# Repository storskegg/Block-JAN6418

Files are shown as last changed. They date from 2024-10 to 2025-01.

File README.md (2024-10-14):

# Block-JAN6418

A simple yet flexible gain stage based on the JAN6418 subminiature pentode.

## Features

- Filament supply options:
    - 2x resistor voltage drop
    - LM317L direct regulation
- Pentode/Triode mode:
    - Triode: Jumper (0 Ohm resistor) S2 to the plate
    - Pentode: Solder a resistor between S2 and the plate, and S2 and ground
    - Pentode: Solder leads to an off-board potentiometer in lieu of the two
      resistors
- Star ground: Every on-board ground connection has its own trace to `Sig_gnd`

## Background

I've been designing a blues harp preamp for a buddy of mine, and it occurred to
me that all valve gain blocks are essentially the same, just with some variance
in component values. Because I tend to have different ideas for an individual
gain block, and different ideas about interstage connections (capacitor types,
tone stack, delay/echo, etc), having this board allows me to play with different
ideas more easily than pulling up components from the breadboard, but at the
cost of components soldered into place.

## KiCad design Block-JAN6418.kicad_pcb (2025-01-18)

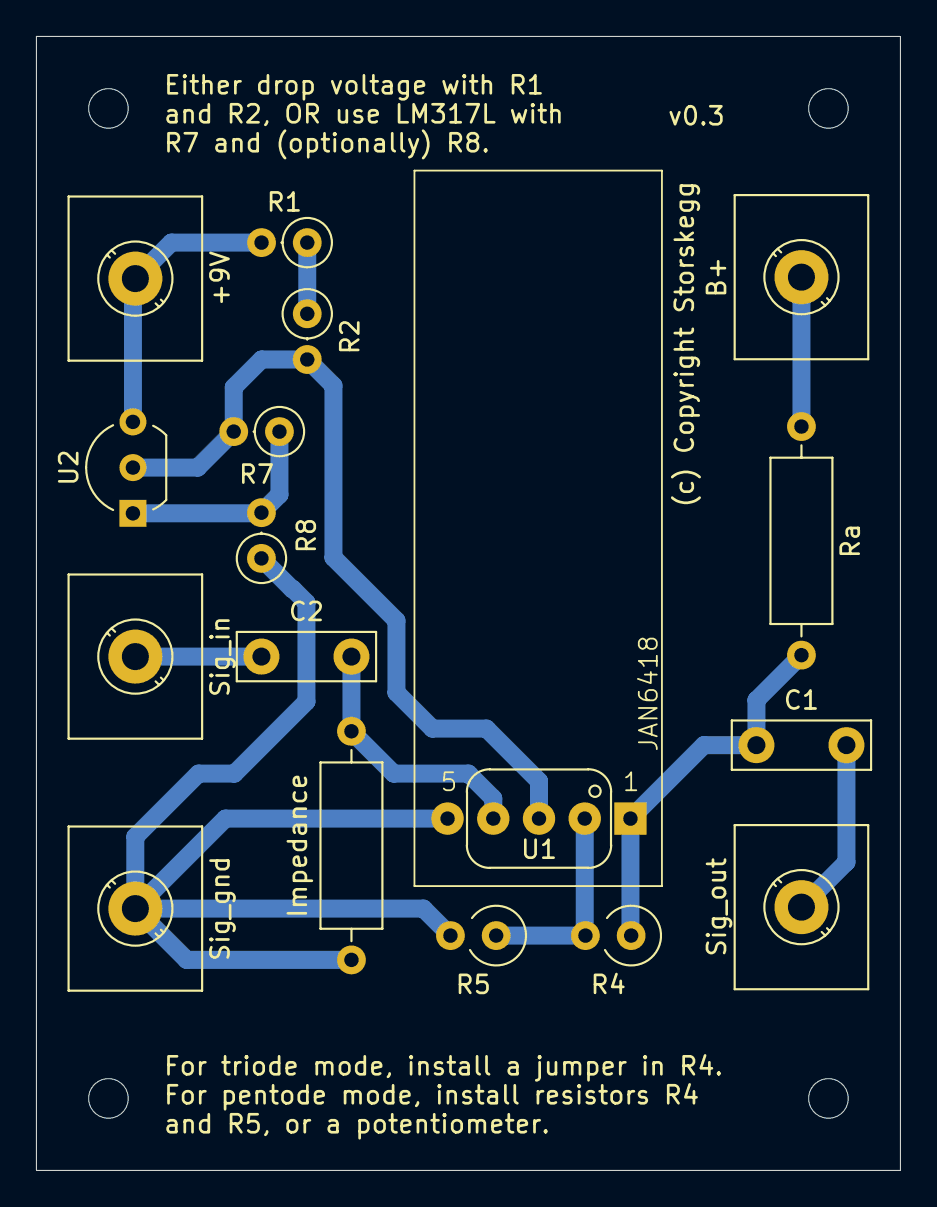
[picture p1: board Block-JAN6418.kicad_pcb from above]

Board: 2 copper layers, 48.0 x 63.0 mm, 17 parts (0 on the bottom side), 11 nets.

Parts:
+9V: 9V; TerminalBlock_MetzConnect_360271_1x01_Horizontal_ScrewM3.0_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
B+: B+; TerminalBlock_MetzConnect_360271_1x01_Horizontal_ScrewM3.0_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
C1, C2: C; C_Disc_D7.5mm_W2.5mm_P5.00mm
Impedance: 1M; R_Axial_DIN0309_L9.0mm_D3.2mm_P12.70mm_Horizontal
R1: R_FilA; R_Axial_DIN0207_L6.3mm_D2.5mm_P2.54mm_Vertical
R2: R_FilB; R_Axial_DIN0207_L6.3mm_D2.5mm_P2.54mm_Vertical
R4: R_TriPenA; R_Axial_DIN0309_L9.0mm_D3.2mm_P2.54mm_Vertical
R5: R_PenB; R_Axial_DIN0309_L9.0mm_D3.2mm_P2.54mm_Vertical
R7: R_r1; R_Axial_DIN0207_L6.3mm_D2.5mm_P2.54mm_Vertical
R8: R_r2; R_Axial_DIN0207_L6.3mm_D2.5mm_P2.54mm_Vertical
Ra: Ra; R_Axial_DIN0309_L9.0mm_D3.2mm_P12.70mm_Horizontal
Sig_gnd: Sig_gnd; TerminalBlock_MetzConnect_360271_1x01_Horizontal_ScrewM3.0_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
Sig_in: Sig_in; TerminalBlock_MetzConnect_360271_1x01_Horizontal_ScrewM3.0_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
Sig_out: Sig_out; TerminalBlock_MetzConnect_360271_1x01_Horizontal_ScrewM3.0_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
U1: JAN6418; Valve_Mini_Pentode_Linear
U2: LM317L; TO-92_Inline_Wide

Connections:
+9V: +9V.1, R1.2, U2.3 (VI)
GND: Impedance.2, R5.2, R8.1, Sig_gnd.1, U1.5 (F+,G3)
unnamed: B+.1, Ra.1
unnamed: C2.1, Sig_in.1
unnamed: C1.2, Sig_out.1
unnamed: R1.1, R2.1
unnamed: C2.2, Impedance.1, U1.4 (G1)
unnamed: R4.2, R5.1, U1.2 (G2)
unnamed: C1.1, R4.1, Ra.2, U1.1
unnamed: R7.1, R8.2, U2.1 (ADJ)
unnamed: R2.2, R7.2, U1.3 (F+,G3), U2.2 (VO)

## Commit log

2024-10-14 Add project files
    [Block-JAN6418-B_Cu.gbr, Block-JAN6418-B_Mask.gbr, Block-JAN6418-B_Paste.gbr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]
2024-10-17 narrow the board, and add some additional silkscreening
    [Block-JAN6418-B_Cu.gbr, Block-JAN6418-B_Mask.gbr, Block-JAN6418-B_Paste.gbr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]
2025-01-19 generate drl, grbrs, update sch from pcb
    [Block-JAN6418-B_Cu.gbr, Block-JAN6418-B_Mask.gbr, Block-JAN6418-B_Paste.gbr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]

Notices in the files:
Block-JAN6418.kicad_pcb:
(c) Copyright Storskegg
